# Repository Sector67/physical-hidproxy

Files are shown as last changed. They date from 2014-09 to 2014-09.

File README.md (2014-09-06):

A Physical HID proxy
====================

So we have an Android phone running some security-sensitive software, as a prototype.
Part of the software is that is has to "pretend" to be a keyboard on a computer.
An Android phone can't do this without the kernel being recompiled.
This project gets around that limitation by using a USB=>FTDI cable connected to
an Arduino running V-USB HID, which sets itself up as a keyboard.
Every SerialEvent, V-USB's keypress command is called.
Thus, every character over serial ends up being typed, which is a hack, but works ;)

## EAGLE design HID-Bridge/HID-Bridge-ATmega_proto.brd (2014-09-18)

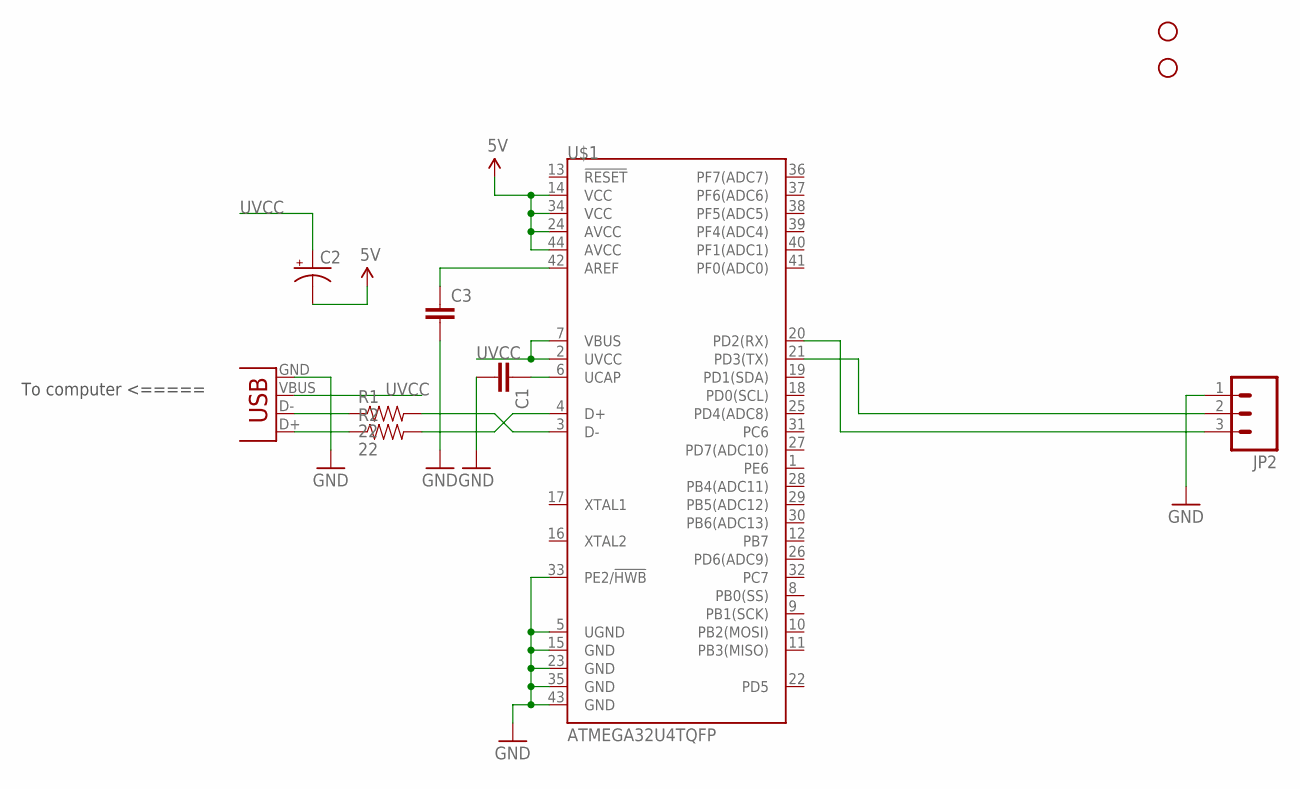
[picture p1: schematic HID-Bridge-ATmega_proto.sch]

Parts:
C1, C3: CAPPTH; CAP-PTH-SMALL
C2: 10UF-25V-20%(PTH); CPOL-RADIAL-10UF-25V
JP1: USB-B; USB-B-PTH
JP2: M03PTH; 1X03
R1, R2: 22; AXIAL-0.1
STANDOFF1, STANDOFF2: STAND-OFF
U$1: ATMEGA32U4TQFP; SPARKFUN-DIGITALIC_TQFP44

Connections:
5V: C2.2 (-), U$1.14 (VCC), U$1.24 (AVCC), U$1.34 (VCC), U$1.44 (AVCC)
GND: C1.2, C3.2, JP1.GND, JP2.1, U$1.5 (UGND), U$1.15 (GND), U$1.23 (GND), U$1.33 (PE2/!HWB), U$1.35 (GND), U$1.43 (GND)
unnamed: JP1.D-, R1.P$1 (1)
unnamed: JP1.D+, R2.P$1 (1)
unnamed: R1.P$2 (2), U$1.3 (D-)
unnamed: R2.P$2 (2), U$1.4 (D+)
unnamed: C1.1, U$1.6 (UCAP)
unnamed: C3.1, U$1.42 (AREF)
unnamed: JP2.3, U$1.20 (PD2(RX))
unnamed: JP2.2, U$1.21 (PD3(TX))
UVCC: C2.1 (+), JP1.VBUS, U$1.2 (UVCC), U$1.7 (VBUS)

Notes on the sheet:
To computer <=====

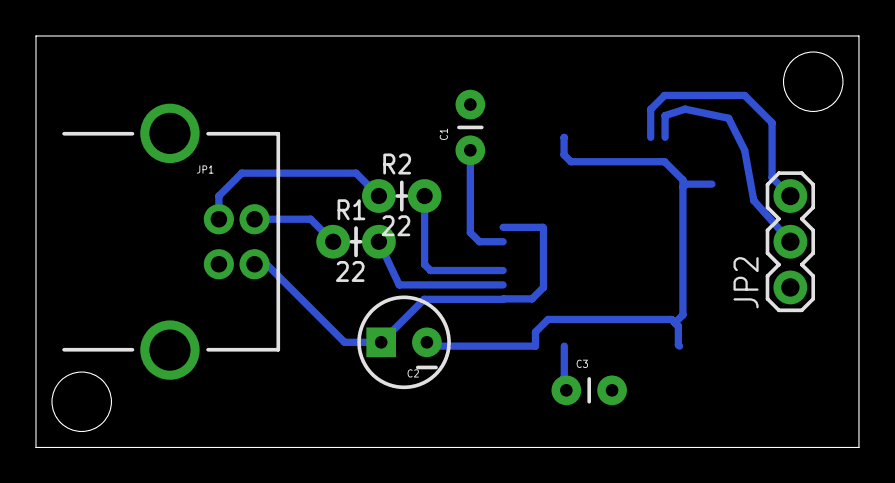
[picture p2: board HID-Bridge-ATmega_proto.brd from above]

Board: 2 copper layers, 45.7 x 22.9 mm, 10 parts (1 on the bottom side), 11 nets.

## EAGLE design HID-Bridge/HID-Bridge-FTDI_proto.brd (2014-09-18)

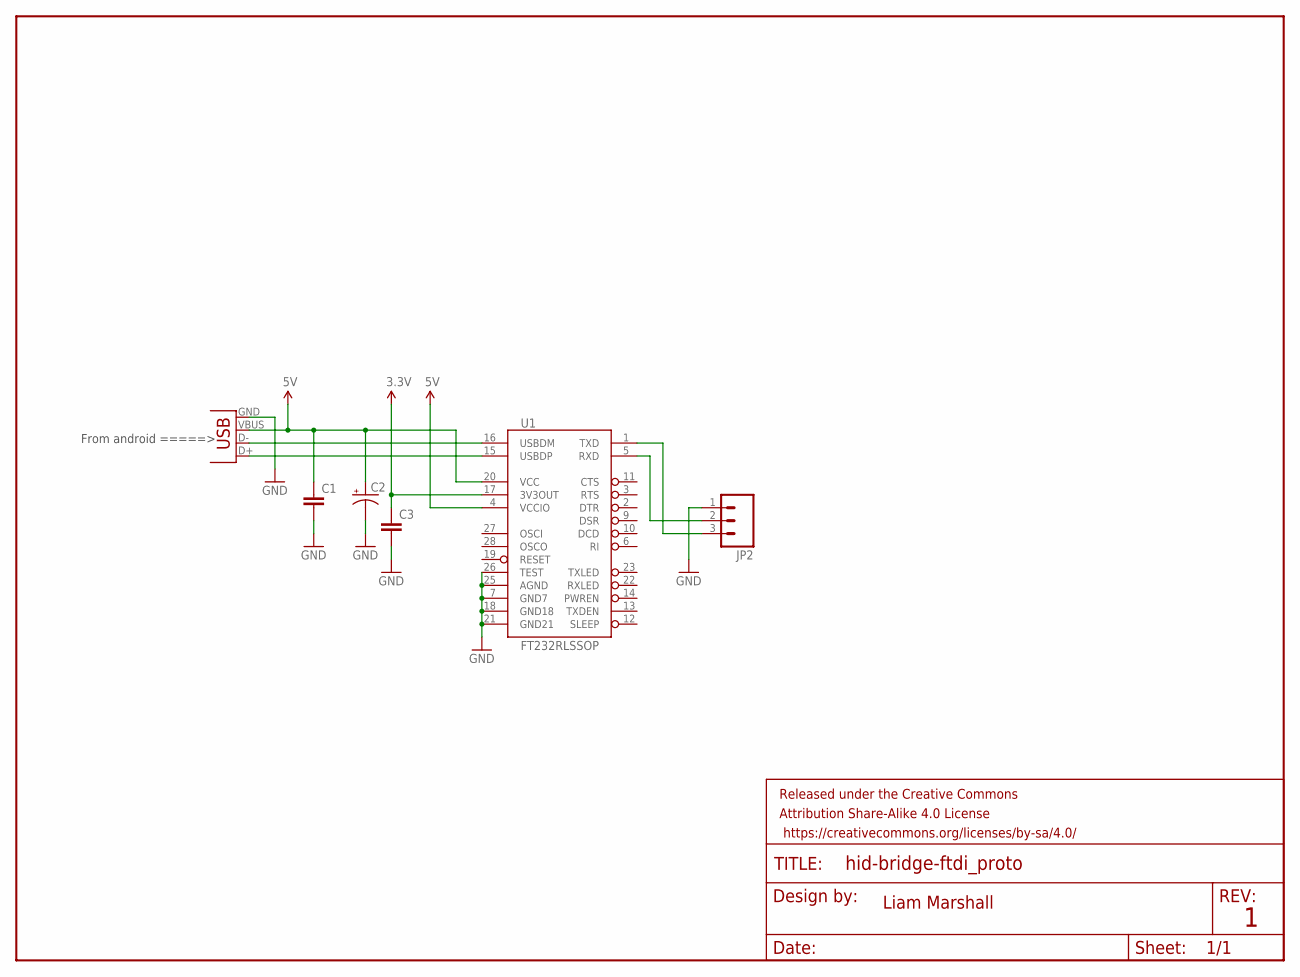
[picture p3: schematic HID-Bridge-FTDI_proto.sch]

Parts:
C1, C3: 0.1UF-50V-20%(PTH)KIT-EZ; CAP-PTH-SMALL-KIT
C2: 10UF-25V-20%(PTH); CPOL-RADIAL-10UF-25V
FRAME1: FRAME-LETTER; CREATIVE_COMMONS
JP1: USB-B; USB-B-PTH
JP2: M03PTH; 1X03
U1: FT232RLSSOP; SSOP28DB

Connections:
3.3V: C3.1, U1.17 (3V3OUT)
5V: C1.1, C2.1 (+), JP1.VBUS, U1.4 (VCCIO), U1.20 (VCC)
GND: C1.2, C2.2 (-), C3.2, JP1.GND, JP2.1, U1.7 (GND7), U1.18 (GND18), U1.21 (GND21), U1.25 (AGND), U1.26 (TEST)
unnamed: JP2.2, U1.5 (RXD)
unnamed: JP1.D+, U1.15 (USBDP)
unnamed: JP1.D-, U1.16 (USBDM)
unnamed: JP2.3, U1.1 (TXD)

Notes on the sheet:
From android =====>
Liam Marshall

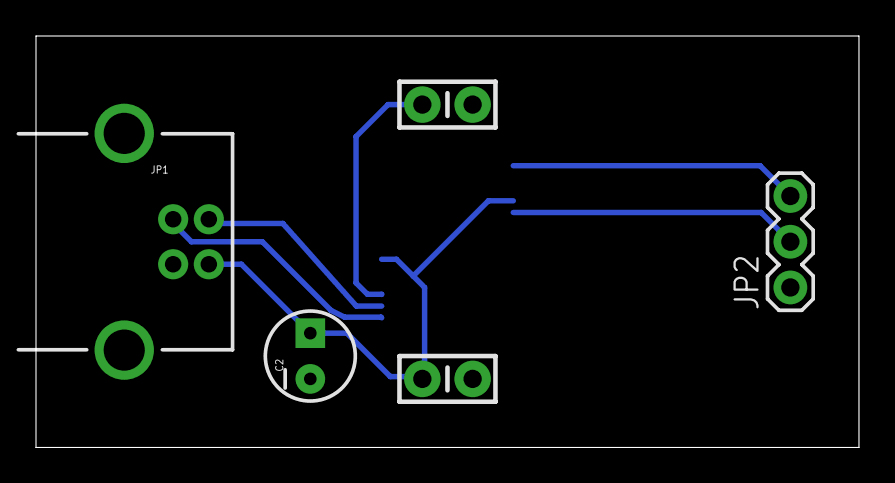
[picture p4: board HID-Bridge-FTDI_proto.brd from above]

Board: 2 copper layers, 45.7 x 22.9 mm, 7 parts (1 on the bottom side), 7 nets.

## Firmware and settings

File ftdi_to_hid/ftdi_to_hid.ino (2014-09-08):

void setup() {
   // open the serial port. Note that it is Serial1 and not just Serial
   Serial1.begin(19200);
   //wait for the serial port to become available
   while (!Serial1){;}
   //start the keyboard
   Keyboard.begin();
}

void loop() {
   // check for incoming serial data:
   if (Serial1.available() > 0) {
     // read incoming serial data:
     char inChar = Serial1.read();
     // Send that character to the keyboard:
     Keyboard.write(inChar);
   }
}

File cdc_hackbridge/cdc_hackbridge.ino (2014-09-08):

#include <SoftwareSerial.h>

#define USE_SOFTSERIAL
#define SS_RX 14
#define SS_TX 16

SoftwareSerial toAndroid(SS_RX, SS_TX);

void setup() {
  Keyboard.begin();
  
  toAndroid.begin(19200);
}

void loop() {
	if (toAndroid.available() > 0) {
		char key = toAndroid.read();
		Keyboard.press(key);
		delay(25);
		Keyboard.release(key);
	}
}

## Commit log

2014-09-06 no arduino right now. get it working first ;)
2014-09-06 Arduino test
2014-09-16 Add board files for FTDI -> Serial adaptor (5v, single side)
    [HID-Bridge-FTDI_proto.brd, HID-Bridge-FTDI_proto.sch]
2014-09-16 Changes for sides etc.
    [HID-Bridge-FTDI_proto.brd, HID-Bridge-FTDI_proto.sch]
2014-09-16 Added name
    [HID-Bridge-FTDI_proto.brd]
2014-09-18 Changes on FTDI, larger clearance &c
    [HID-Bridge-FTDI_proto.brd, HID-Bridge-FTDI_proto.sch]
2014-09-18 Initial commit of ATmega board
    [HID-Bridge-ATmega_proto.brd, HID-Bridge-ATmega_proto.sch]

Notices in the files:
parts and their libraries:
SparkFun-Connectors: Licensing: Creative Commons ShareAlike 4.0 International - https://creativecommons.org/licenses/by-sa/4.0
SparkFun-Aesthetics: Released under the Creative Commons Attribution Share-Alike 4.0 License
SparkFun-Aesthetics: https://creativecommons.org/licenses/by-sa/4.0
